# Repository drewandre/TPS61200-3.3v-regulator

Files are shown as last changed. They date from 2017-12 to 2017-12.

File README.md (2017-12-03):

# TPS61200 3.3v regulator with Soft Power Switch

Low-noise TPS61200 3.3v regulator with soft power circuitry.

When user depresses momentary switch, p-mosfet channel is opened and pin 6 of the TPS61200 (EN / enable pin) is pulled HIGH. This turns the regulator on and supplies a steady, low-noise 3.3v output. ***Important:*** Microcontroller needs to write a digital HIGH to the KILL pin upon startup to keep channel open and regulator turned on.

To turn, MCU should write a digital LOW to the KILL pin. This closes the p-channel mosefet and turns off regulator.

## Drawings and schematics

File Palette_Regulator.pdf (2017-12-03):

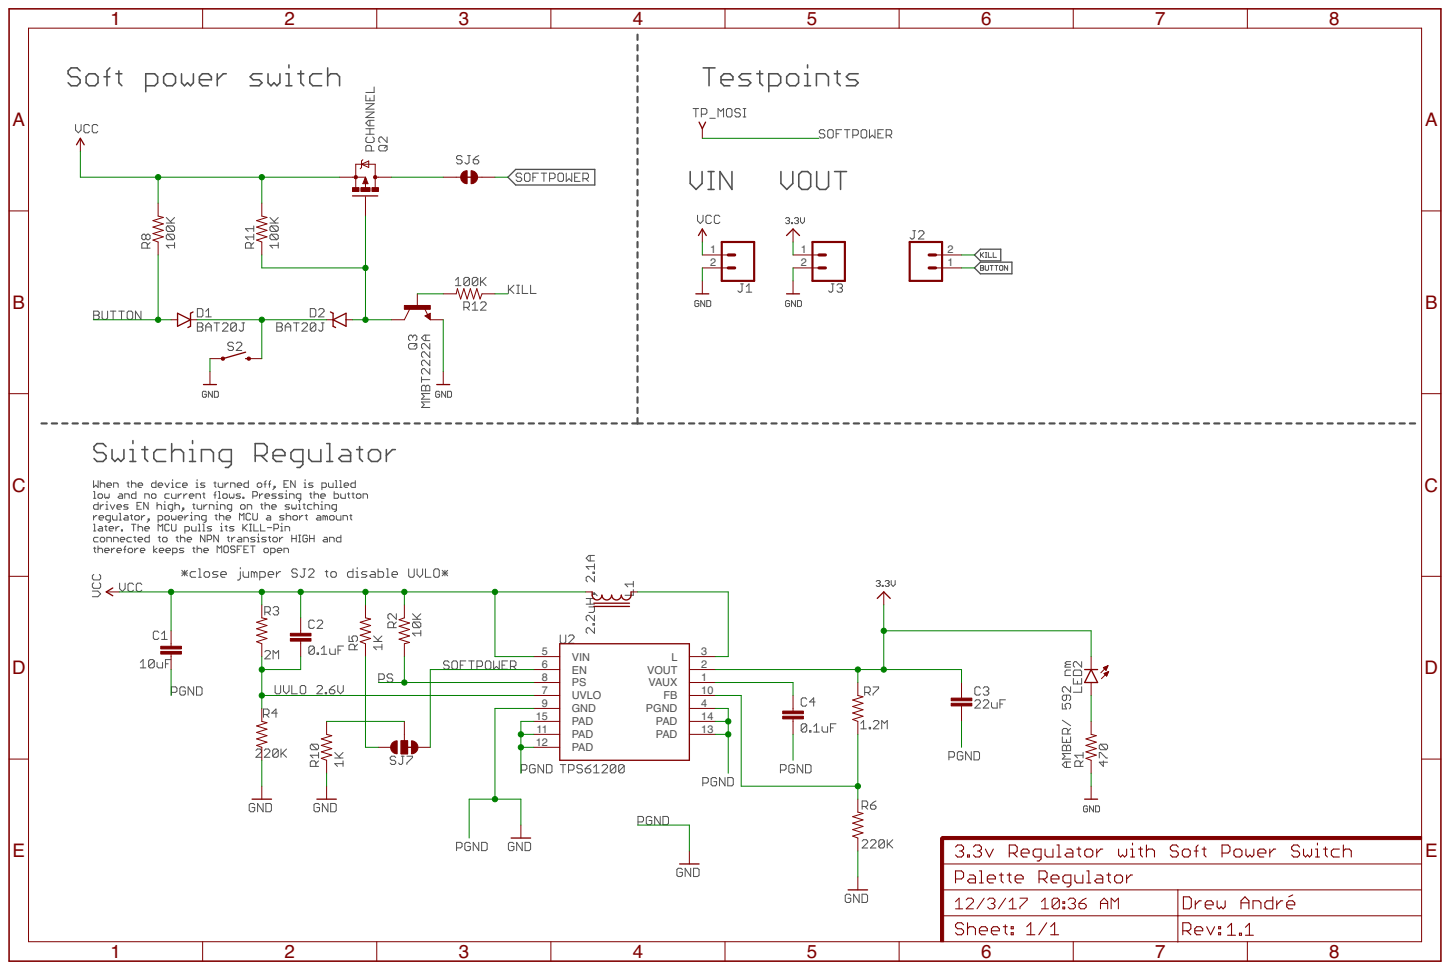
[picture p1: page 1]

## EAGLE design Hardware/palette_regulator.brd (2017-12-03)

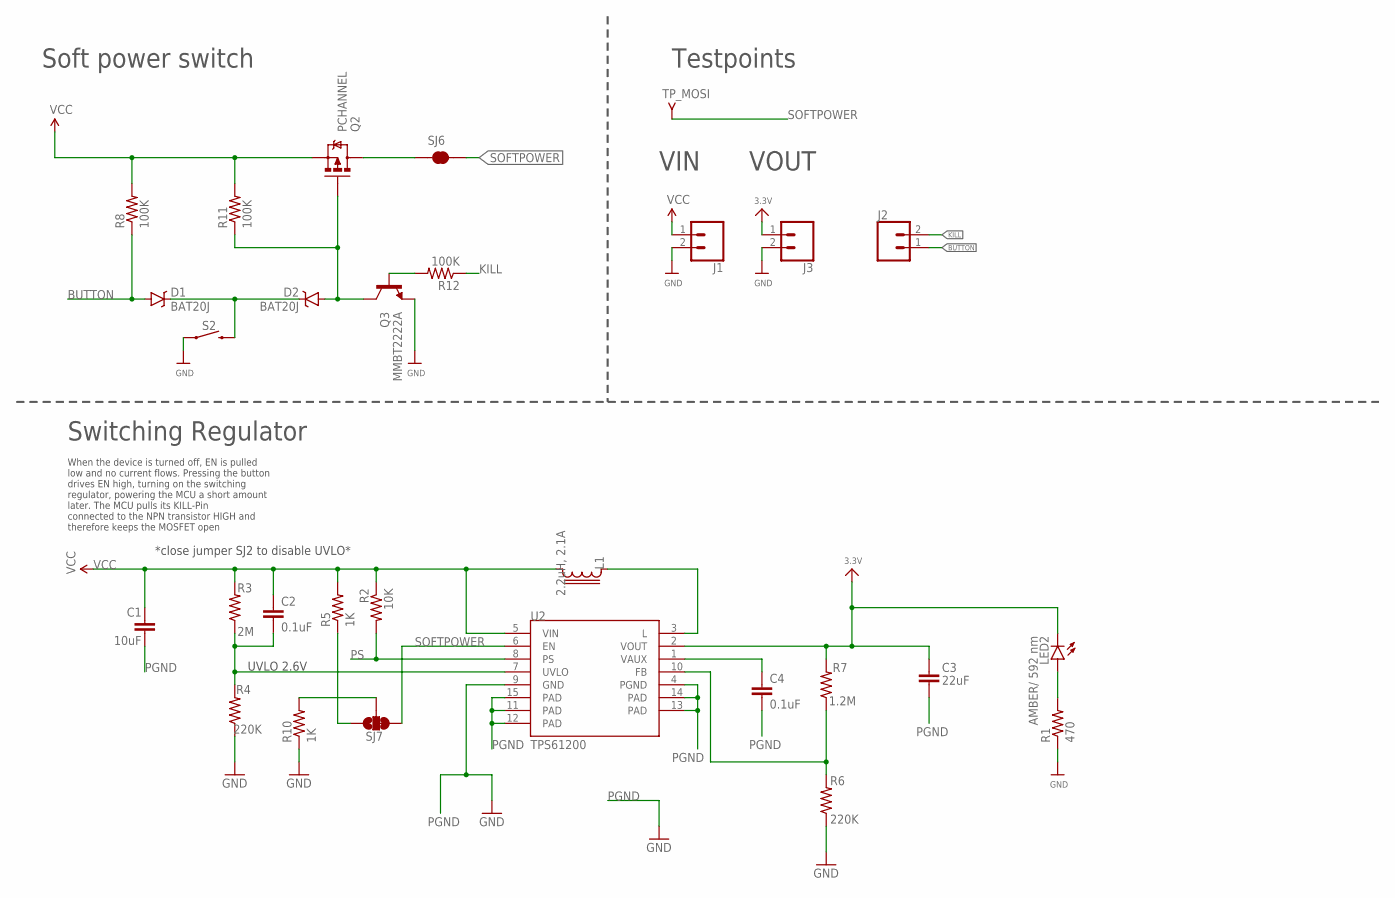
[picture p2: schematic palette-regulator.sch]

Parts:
C1: 10uF; 0603-CAP
C2, C4: 0.1uF; 0603-CAP
C3: 22uF; 0603-CAP
D1, D2: BAT20J; SOD-323
J1, J2, J3: CONN_02; 1X02
L1: 2.2uH, 2.1A; LPS3015
LED2: AMBER/ 592 nm; LED-0603
Q2: PCHANNEL; SOT23-3; MPN BSS84LT1G
Q3: MMBT2222A; SOT23-3
R1: 470; 0603-RES
R2: 10K; 0603-RES
R3: 2M; 0603-RES
R4, R6: 220K; 0603-RES
R5, R10: 1K; 0603-RES
R7: 1.2M; 0603-RES
R8, R11, R12: 100K; 0603-RES
S2: MOMENTARY-SWITCH-SPST-PTH-6.0MM; TACTILE_SWITCH_PTH_6.0MM; MPN PTS645SH50SMTR 92 LFS
SJ6: JUMPER-PAD-2-NC_BY_TRACE; PAD-JUMPER-2-NC_BY_TRACE_YES_SILK
SJ7: JUMPER-PAD-3-2OF3_NC_BY_TRACE; PAD-JUMPER-3-2OF3_NC_BY_TRACE_YES_SILK_FULL_BOX
TP_MOSI: MOSI; PAD-016
U2: TPS61200; QFN-10_PAD

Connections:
3.3V: C3.1, J3.1, LED2.C, R7.2, U2.2 (VOUT)
BUTTON: D1.A, J2.1, R8.1
FB: R6.2, R7.1, U2.10 (FB)
GND: J1.2, J3.2, Q3.2 (E), R1.1, R4.1, R6.1, R10.1, S2.1
KILL: J2.2, R12.1
unnamed: R10.2, SJ7.2
unnamed: L1.1, U2.3 (L)
unnamed: D2.A, Q2.1 (G), Q3.3 (C), R11.1
unnamed: Q3.1 (B), R12.2
unnamed: R5.1, SJ7.1
unnamed: D1.C, D2.C, S2.3 (2)
unnamed: Q2.3 (D), SJ6.1
unnamed: LED2.A, R1.2
PGND: C1.2, C3.2, C4.2, U2.4 (PGND), U2.9 (GND), U2.11 (PAD), U2.12 (PAD), U2.13 (PAD), U2.14 (PAD), U2.15 (PAD)
PS: R2.2, U2.8 (PS)
SOFTPOWER: SJ6.2, SJ7.3, TP_MOSI.1, U2.6 (EN)
UVLO: C2.2, R3.1, R4.2, U2.7 (UVLO)
VAUX: C4.1, U2.1 (VAUX)
VCC: C1.1, C2.1, J1.1, L1.2, Q2.2 (S), R2.1, R3.2, R5.2, R8.2, R11.2, U2.5 (VIN)

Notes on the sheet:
UVLO 2.6V
*close jumper SJ2 to disable UVLO*
Switching Regulator
When the device is turned off, EN is pulled low and no current flows. Pressing the button drives EN high, turning on the switching regulator, powering the MCU a short amount later. The MCU pulls its KILL-Pin connected to the NPN transistor HIGH and therefore keeps the MOSFET open
Soft power switch
Testpoints
VIN
VOUT

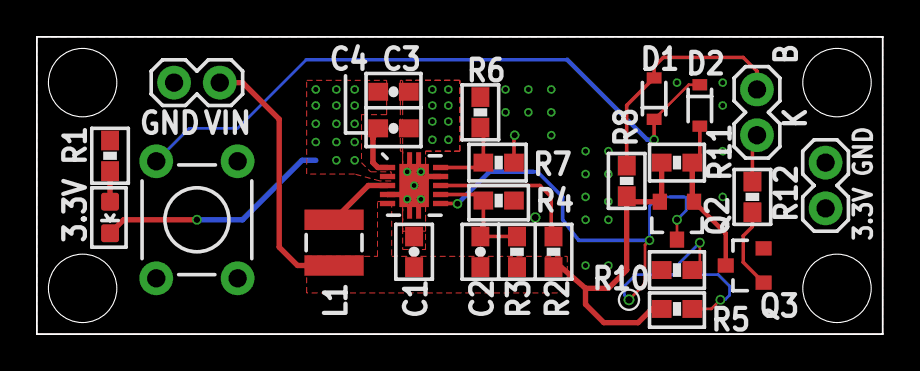
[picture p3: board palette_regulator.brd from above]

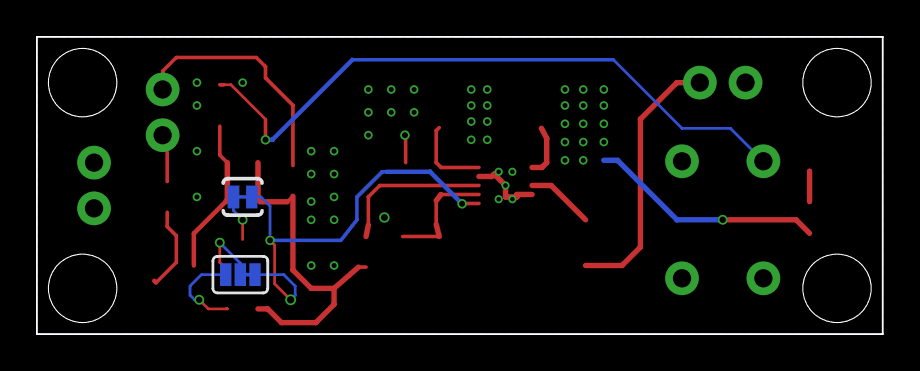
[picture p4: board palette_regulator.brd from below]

Board: 4 copper layers, 47.0 x 16.5 mm, 29 parts (2 on the bottom side), 19 nets.

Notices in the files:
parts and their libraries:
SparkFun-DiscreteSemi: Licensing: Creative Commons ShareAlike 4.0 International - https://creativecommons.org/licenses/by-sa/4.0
